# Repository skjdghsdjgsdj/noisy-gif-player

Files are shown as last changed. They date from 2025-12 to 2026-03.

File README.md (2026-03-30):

# Noisy GIF Player

## What is it?

It's a little portable device with a tiny screen and speaker to play animated GIFs, along with sound, from a microSD card.

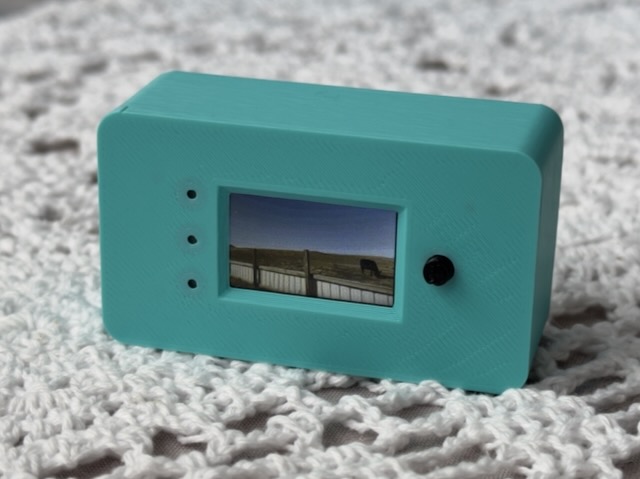
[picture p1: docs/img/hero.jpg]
Hero image (actual product)

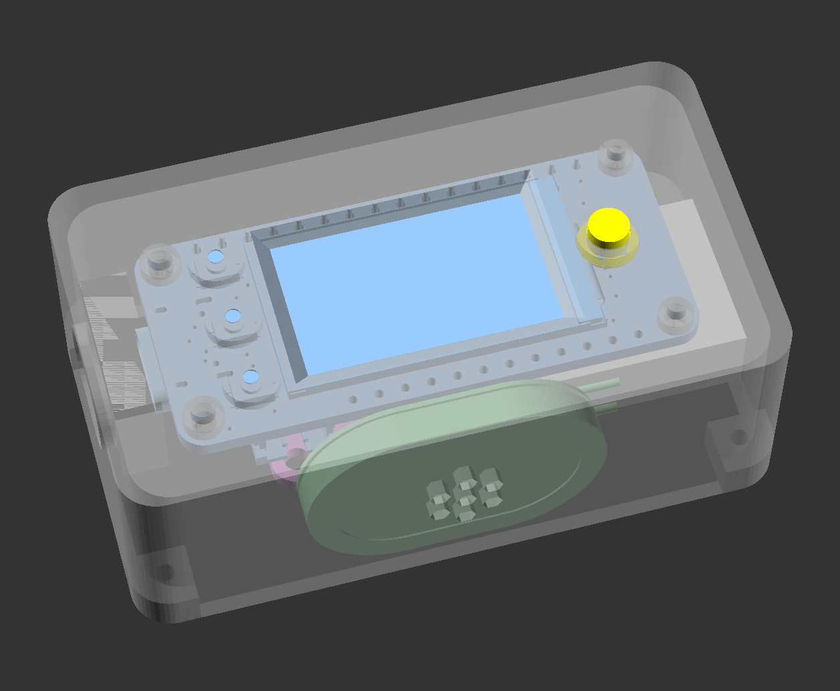
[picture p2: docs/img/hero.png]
Hero image (render)


## How do I build one?

You need:

* Some parts listed below
* Some soldering experience
* A 3D printer
* A computer:
  * Running macOS or Linux
  * With a microSD card reader
  * With FFmpeg installed

> [!NOTE]
> Linux/macOS is needed because the script that creates compatible GIFs/WAVs is written in Bash. On Windows, you'll need to port it to PowerShell, like `convert.ps1`. PRs welcome!

### Step 1: Buy parts

You need these parts:

| Part | Purpose | Price (USD) |
|---|---|---|
| [Adafruit ESP32-S3 Reverse TFT Feather](https://www.adafruit.com/product/5691) | The brains of the project, plus an LCD | $24.95 |
| [Adafruit SDIO breakout](https://www.adafruit.com/product/4682) | Stores GIFs and WAVs | $3.50 |
| [Adafruit I2S MAX98357A breakout](https://www.adafruit.com/product/3006) | Plays audio to a speaker | $5.95 |
| [Mini oval speaker](https://www.adafruit.com/product/3923) | An itty bitty speaker | $1.95 |
| [Female headers for Feathers](https://www.adafruit.com/product/2886) | Physical assembly | $0.95 |
| [400mAH battery for Feathers](https://www.adafruit.com/product/3898) | The battery | $6.95 |
| **Total** | | **$44.25**  |

You'll need these supplies:

* [Solid core hookup wire](https://www.adafruit.com/product/1311)
* Some screws:
  * 2&times; M2.5x4 screws
  * 2&times; M2x4 screws
  * 4&times; [countersunk self-tapping M2x6 screws](https://www.amazon.com/dp/B09DB5SMCZ?th=1)
* A microSD card (almost any size)
* A paperclip
* A USB C cable

### Step 2: Print the enclosure

Print the following parts. Use 0.2mm or smaller layer height. Infill settings don't matter. The STLs are in the latest release download on GitHub.

* Print `Case.stl` with the screen opening on the print bed. Use paint-on supports for the four screw holes in the corners of the case.
* Print `Backplate.stl` with the two ribs facing upwards.
* Print `Button.stl` with the wider part of the button on the print bed.

If your printer doesn't bridge well, also add supports to the USB C hole in `Case.stl`.

### Step 3: Make a GIF

The repository includes a script called `convert.sh` that runs FFmpeg with very specific arguments to make GIFs and WAVs compatible with the board.

> [!IMPORTANT]
> At least one GIF must be loaded onto the SD card for the project to function. Each GIF must follow a very specific format. A random GIF you find on the internet is unlikely to work. Here's how to make a compatible GIF and WAV.

First, prepare your environment. This only needs to be done once:

1. In a terminal, `cd` to the project's directory and the `software/server` directory, then run `chmod +x convert.sh` to make the conversion script executable.
2. Format your SD card as FAT32.
3. Create two directories in the root: `gifs` and `wavs`.

Now, convert a video into a compatible GIF and WAV format:

1. Download a video to your computer that you want to load. Pick a video that's only a few seconds long because longer ones might drift out of audio sync. Let's assume it's called `test.mp4` and you stored it in the same directory as this project.
2. Open a terminal and `cd` to the project's directory.
3. Run `./convert.sh test.mp4`. This outputs `test.gif` and the `test.wav` in the same directory.
4. Copy `test.gif` to `gifs/` and `test.wav` to `wavs/`.

The resulting SD card structure should look like:

```
SD card root
 ├── gifs/
 │   └── test.gif
 └── wavs/
     └── test.wav
```

### Step 4: Physical assembly

> [!IMPORTANT]
> Read these instructions fully before actually starting! Everything is a very tight fit in the enclosure and the details matter.

Here's a logical diagram of how the components are connected, for reference. In particular, note the following:

* The Feather's `GND` pin is shared, but two separate `3V` pins are used
* The I2S amplifier aligns to `MI` through `TX`; the _first_ 3V pin gets wired to the I2S amplifier's power pin
* The SD breakout aligns to the _second_ 3V pin, the GND pin, and various GPIO pins up through `SCK`; all the SD breakout's connections are through headers, not wires
* `RST`, `MO`, and `DB` are unused on the row of 16 pins
* None of the pins on the row of 12 pins are used

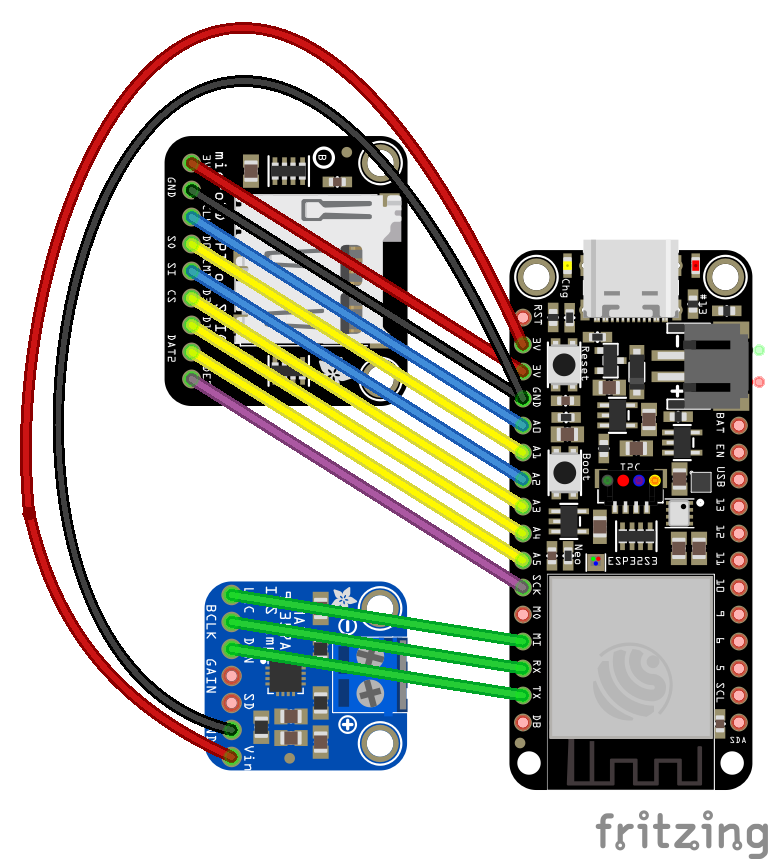
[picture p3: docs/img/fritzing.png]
Fritzing diagram


The male headers that come with the boards may not match the number of pins. You can twist apart the male headers at the perforations to get the right number of pins.

Some assembly tips:

* A magnetized screwdriver will help a lot. It's tricky to align the screws when everything is shoved in the case otherwise.
* For the doubled-up `GND` pin: try sandwiching the ground wire between the female header on the Feather and the Feather itself. That is, for the female header, the `GND` pin hole will have both the female header's pin and the ground wire going through it, then soldered in one bit. The female header might be a bit out of level, but as long as all the pins are making good contact once soldered, it should still fit.
* When viewing the case from above with the screen facing down and the USB port hole to the left, and therefore the speaker hole on the top, offset the speaker a bit to the right (i.e., away from the USB C hole). If you try to perfectly center it, you may find that the battery plug gets in the way of fitting everything into the case.

1. Solder headers to various boards. Be sure you get the pins right! You will not use all the headers!
   1. Solder the 16-pin female header to the Feather's row of 16 pins (`RST` through `DB`). **Do not solder the 12-pin female header.** The female portion of the header is on the opposite of the board as the LCD, like this:
   
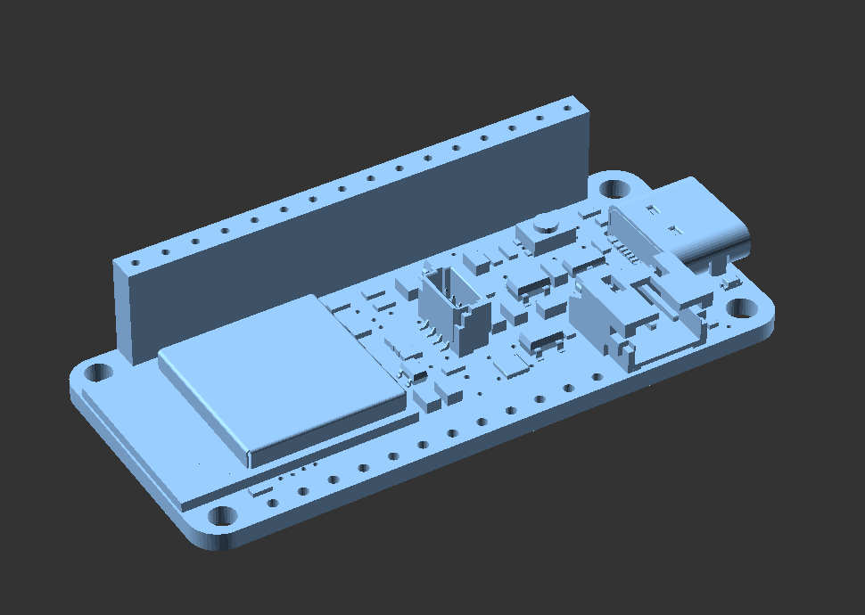
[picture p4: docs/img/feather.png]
Feather with female headers
      
      
   2. Solder a male header to the SD card breakout. The SD card slot faces up and the male header faces down, like this:
   
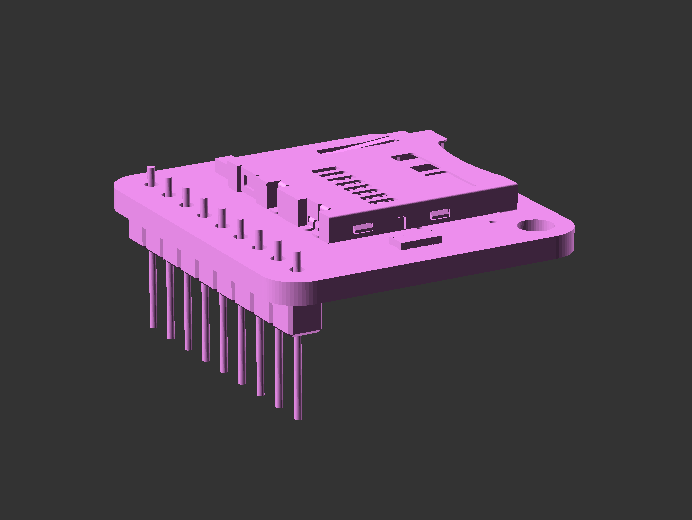
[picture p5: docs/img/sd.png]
SD card breakout with male headers
      

   3. Solder a male header **with only three** pins to the I2S amplifier breakout. Solder the `LRC`, `BCLK`, and `DIN` pins like this. Note that in this picture, the screw terminals if included with your board aren't shown, but would be on the top with the headers facing down. The components are also on the top.

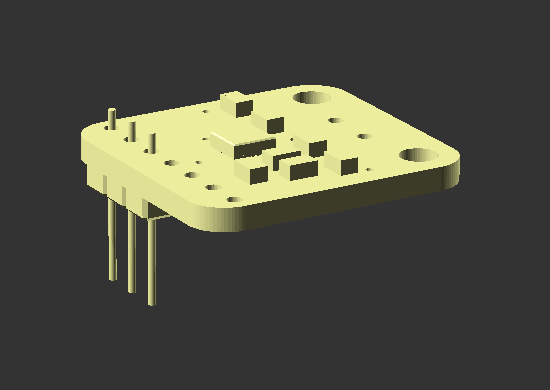
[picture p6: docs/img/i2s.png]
I2S amplifier with male headers
      

2. If your I2S amplifier came with presoldered screw terminals, you'll need to remove them because they take up too much space. Gently twist and rock them back and forth a whole bunch until you can work them free, or if you're able, desolder the pins. Be careful and take your time.

3. Now you'll connect the speaker to the I2S amplifier.

   1. Cut the tiny male JST connector off the speaker. You'll need every bit of wire possible, so cut off the connector as close to the wires as possible.
   2. Strip about 3 mm from the red and black wires from the speaker. The wire is very thin and you won't have much to work with, so be careful!
   3. Solder the black wire to the `-` pin on the I2S amplifier. This is one of the pins that are now exposed after you removed the screw terminals.
   4. Solder the red wire to the `+` pin.

4. Lastly, you need to solder a couple wires to the I2S amplifier for power and ground. This isn't necessary for the SD breakout because the pins already line up. Once you're done, the `GAIN` and `SD` pins should be unoccupied, but the other pins all connected to either headers or wires.

   1. Cut a black wire about 5 cm long and strip both ends at about 3 mm. Solder one end to the `GND` pin on the I2S amplifier. Solder the other end to the `GND` pin on the SD breakout. This means that the `GND` pin on the SD breakout will be soldered to both a male header pin and the wire, so it'll be tricky to solder.
   2. Cut a red wire about 5 cm long. Strip one end to 3 mm, and the other to about 6 mm. Solder the 3mm end to the `VIN` pin of the I2S amplifier. Leave the other end free for now.

5. Install the parts into the enclosure:

   1. Place the tiny 3D printed button in its hole. The narrow end goes through the front of the case. The wider part keeps it in place, like this:

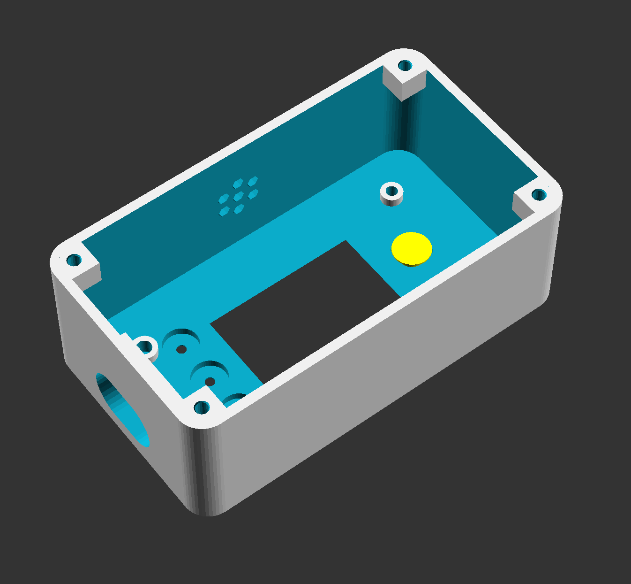
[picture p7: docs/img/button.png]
Button in place
      

   2. Connect the battery to the Feather. Definitely from this point onwards be careful aligning things and poking around with screwdrivers so you don't short any components!
   
   3. Screw the Feather into place. Use the M2.5x4mm screws for the larger holes and M2x4mm screws for the smaller ones. Only tighten them enough to keep the board in place. Overtightening will easily strip the plastic and you'll need to reprint the case. Once done, test pressing the button to make sure it moves freely and actuates the reset button on the Feather itself.

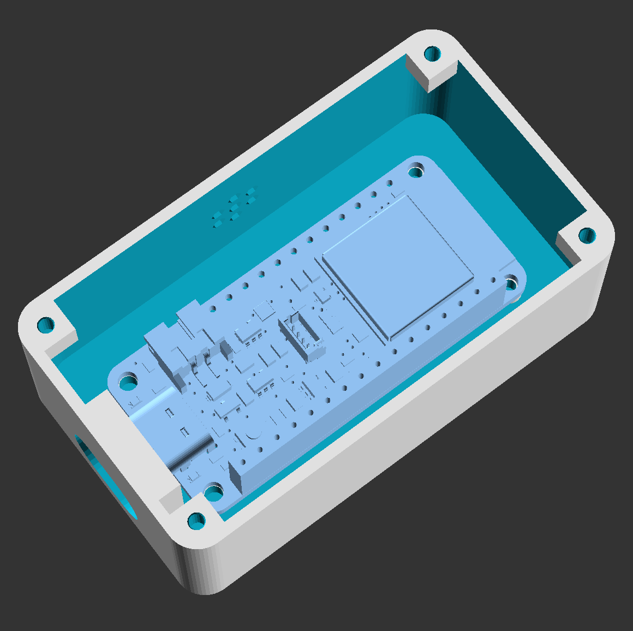
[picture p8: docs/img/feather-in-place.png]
Feather in place
      

   4. Insert your microSD card into the SD reader, then install the SD reader and I2S amplifier. Note the alignment. **Be sure to align them to the pins shown!** The first two pins closest to the USB C port should be empty, along with the last pin closest to the ESP32. When doing so, tuck the battery under the breakouts (the white box).

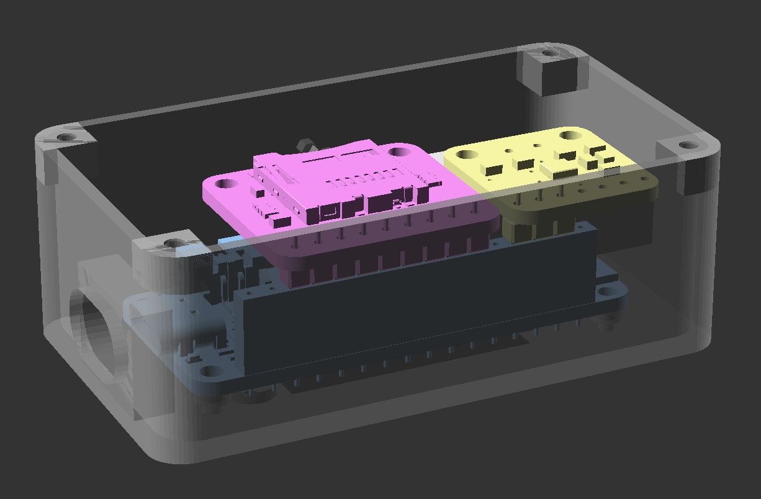
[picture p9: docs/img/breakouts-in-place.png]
Breakouts in place
      
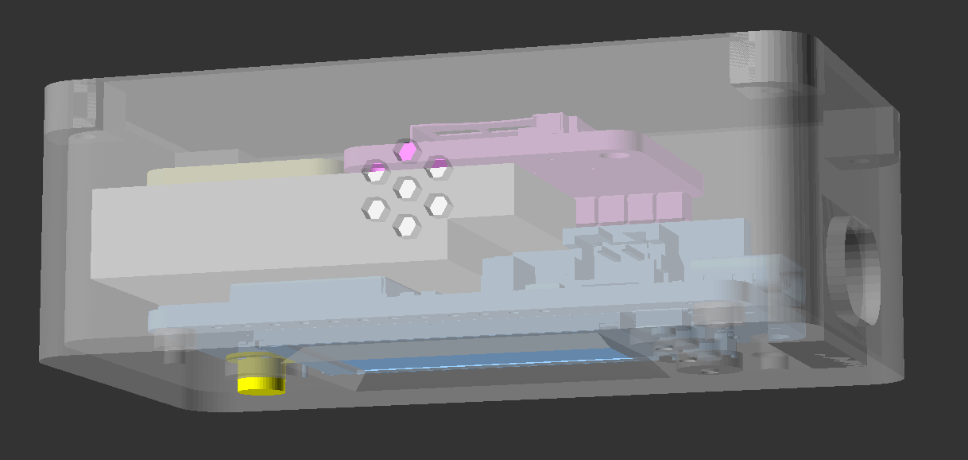
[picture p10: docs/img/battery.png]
      

   5. Take the loose end of the red wire and put it in the second pin closest to the USB C port (`3V`) of the female header.

   6. Remove the white cover for the adhesive on the sticker, and shove it into place by the speaker hole with the grille facing outwards. It may be tricky to maneuver it around the battery connection.

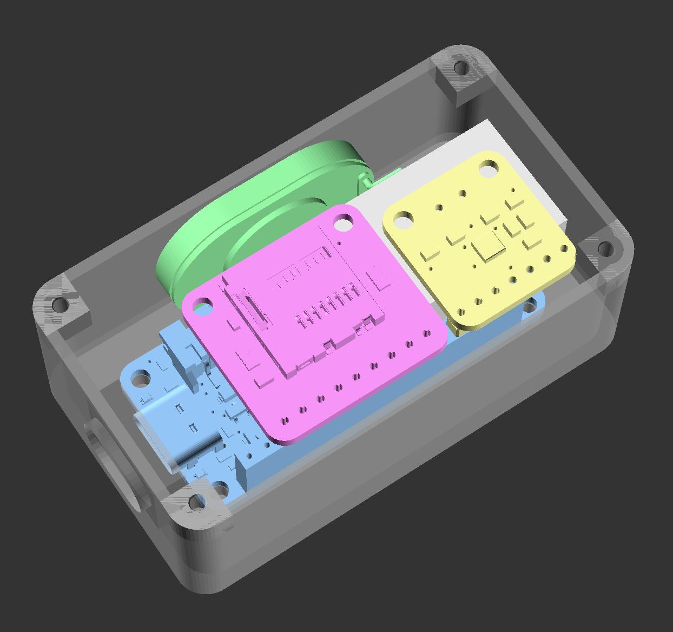
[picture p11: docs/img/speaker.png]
Speaker in place
      

6. You're done! Screw the backplate on with the ribs facing inward by the components using the self-tapping screws.

### Step 5: Software installation

1. Install the Arduino IDE and set it up for this specific board per [Adafruit's instructions](https://learn.adafruit.com/esp32-s3-reverse-tft-feather/arduino-ide-setup-2).
2. Open `software/Arduino/Arduino.ino` and install the following libraries via Sketch → Include Library → Manage Libraries. Install dependencies if prompted.
   1. "Adafruit GFX Library" by Adafruit
   2. "Adafruit ST7735 and ST7789 Library" by Adafruit
   3. "AnimatedGIF" by Larry Bank
3. Connect the board to your computer via a USB C cable.
4. Using a paperclip, press and hold D0 (top-left pinhole on the board when viewed with the USB port on the left). While holding D0, press the Reset button, then release D0.
5. Connect to the board in the Arduino IDE.
6. Select **Tools** → **Partition Scheme** and "Huge APP (3MB No OTA/1MB SPIFFS)" or a similar entry. This prevents a bootloader screen from appearing if you press the Reset button twice with a specific timing.
7. Select **Tools** → **USB CDC on Boot** and set it to "Disabled." If you don't do this, the USB loading method of files to the SD card may not work.
8. Compile and upload the sketch.

Press the Reset button. Your GIF and WAV should play! Once the GIF is done, the screen fades off and the board sleeps. Pressing the Reset button wakes it back up and a GIF/WAV play again.

## Usage

The physical 3D printed button presses the Reset button on the Feather, playing a random GIF. The code will avoid playing the same GIF twice if more than one GIF is loaded.

The battery should last a long time, but it's not a good idea to let it discharge too deeply. Charge the board with a USB C cable periodically. It is safe to keep a USB cable connected even after the battery is done charging.

### Loading more GIFs

There are two ways to load GIFs and WAVs.

The fastest way for a lot of GIFs and WAVs is directly via the SD card. Consider this option when you first build the project. Once you've built the project, it can be a pain to take it apart to get the SD card out.

The more convenient way is by a USB cable, but transfer speeds are much slower than using the SD card directly:

* Connect the project to your computer via USB C.
* Use a paperclip to hold down the D2 button. When viewed with the USB C port on the left, this is the bottom-left pinhole.
* While holding down D2, press Reset, then release D2.

This reboots the board into USB mass storage mode with a message appearing on the screen stating that USB is connected. A new drive will appear on your computer when connected by USB. The name will be the same as whatever the SD card was named when you formatted it. Once you're done managing the files, eject the drive from your computer, then press the Reset button.

All the GIFs and WAVs you load must be created using the `convert.sh` script! Don't use GIFs or WAVs you find on the internet because they will not likely be compatible with these specs. Always process all your files through `convert.sh`, even if the source itself is a GIF, to be sure it's compatible with the project.

The conversion script can also be invoked with a friendly web interface. If you want to run that, you'll need a Python installation. These instructions assume you have some Python knowledge.

1. Open a terminal and `cd` to the project's `software/server` directory.
2. Set up a Python virtual environment with `python3 -m venv venv` then activate it with `source venv/bin/activate`.
3. Install the necessary libraries with `pip3 install -r requirements.txt`.
4. Run the server: for testing's sake, use `python3 app.py`, or for "production" use (well, just not your own computer), run `chmod +x start.sh` to make the startup script executable, then launch it with `./start.sh`.
5. Open a browser to `http://localhost:5000/`.

### About GIF creation

> [!TIP]
> The WAV for a GIF is optional, so if your source file has no sound, or you just don't want sound, delete the resulting `.wav` file.

`convert.sh` does several things:

* Forces the framerate to 30 fps
* Forces the resolution to exactly 240x135, which is the native resolution of the screen. GIFs are letterboxed or pillarboxed as necessary to keep the aspect ratio and to match this resolution.
* Forces a specific color palette
* Outputs a WAV file at 16 KHz mono

You can pass `--start` and/or `--end` arguments to the conversion script with timecodes to crop a video to a certain timespan if you don't want to convert the entire thing.

## Known issues

* **The OpenSCAD code is terrible and a lot of the math is wrong if you adjust some settings, like surface thickness.** Sure is. I needed to build this quickly so I hardcoded a _lot_ of things. I welcome any attempts to clean up or just completely redo the enclosure code.
* **Some of the Arduino code is also terrible.** Because it is largely and shamefully AI generated for the same reason of time constraints, plus C++ not being my speciality. At least it works.
* **The USB transfer speed is super slow.** That's a limitation of the board. I don't think there's any way to make it faster. If you want to transfer a lot of data, take out the SD card and put it in a card reader.
* **There's no low battery warning.** Yes I should add that. There's an onboard I2C battery monitor that should work for this purpose; I just haven't programmed that in yet.

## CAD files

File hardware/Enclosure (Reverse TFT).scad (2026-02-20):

include <BOSL2/std.scad>
include <BOSL2/shapes3d.scad>

// Diameter of pins (male)
Pin_diameter = 0.5;
// How far pins project from the base of a header into the thru holes
Pin_projection = 3;
// Height of the female-only portion of female headers
Female_header_base_height = 8.5;
// Height of the plastic retaining thing of male headers
Male_header_base_height = 2.6;
// Depth of the plastic retaining thing for headers
Header_base_depth = 2.5;
Male_header_total_height = 11.4;

PCB_height = 1.6;

Surface = 1.5;

/* [Self-tapping screws for the lid including tolerances (M2x6 are defaults)] */
Screw_height = 6.3;
Screw_head_diameter = 4.1;
Screw_head_height = 1.7;
Screw_shaft_diameter = 1.85;
// Distance inset from the corner
Screw_inset = 2;
	
Feather_width = 2 * 25.4;
Feather_depth = 0.9 * 25.4;

Extra_width = 11;
Extra_depth = 11;

Inner_height = 21;

Radius = 4;

Z_offset = -1.5;

USB_C_Z = 3.6;

$fn = 50;

module female_header(pin_count, pitch = 2.54) {
	assert(pin_count >= 1);
	
	for (i = [0 : pin_count - 1]) {
		translate([pitch * i, 0, -Pin_projection])
		cylinder(d = Pin_diameter, h = Pin_projection);
	}
	
	render()
	difference() {
		translate([-pitch / 2, -Header_base_depth / 2, 0])
		cube([pitch * pin_count, Header_base_depth, Female_header_base_height]);
	
		for (i = [0 : pin_count - 1]) {
			translate([pitch * i, 0, 0])
			cylinder(d = Pin_diameter + 0.2, h = Female_header_base_height);
		}
	}
}

module male_header(pin_count, pitch = 2.54) {
	assert(pin_count >= 1);
	
	for (i = [0 : pin_count - 1]) {
		translate([pitch * i, 0, 0])
		
		union() {
			cylinder(d = Pin_diameter, h = Male_header_total_height);
			
			translate([0, 0, -Male_header_base_height / 2 + Male_header_total_height - Pin_projection + pitch / 10])
			cuboid([pitch, Header_base_depth, Male_header_base_height], chamfer = pitch / 10);
		}
	}
}

// Feather specs: https://learn.adafruit.com/adafruit-feather/feather-specification
%color("#99ccff") {
	translate([6.35, 0.05 * 25.4, PCB_height])
	female_header(16);

	//translate([16.45, (0.9 * 25.4) - (0.05 * 25.4), PCB_height])
	//female_header(12);

	import("lib/5691 ESP32 S3 Reverse TFT Feather.stl");
}

%translate([8.9, -1.3, Female_header_base_height + Male_header_base_height + PCB_height])
rotate([0, 0, 0])
color("#ff99ff") {
	translate([2.5, 2.55, -Male_header_total_height + Pin_projection - 0.2])
	male_header(9);

	import("lib/4682 Micro SD Breakout.stl");
}

%translate([35.5, -1.3, PCB_height + Female_header_base_height])
color("#ffffaa") {
	translate([0, 0, Male_header_base_height])
	import("lib/3006 MAX98357.stl");
	translate([1.3, 2.55, -Male_header_total_height + Pin_projection + Male_header_base_height - 0.2])
	male_header(3);
}

%translate([24.5, 5, 4.5]) {
	cube([31, 17, 7.5]);
	
	translate([-5.6, 0, 7.5 - 4.2])
	cube([5.6, 17, 4.2]);
}

%translate([25, 28, 9])
rotate([90, 90, 0])
color("#99ffaa") import("lib/3923 Mini Oval Speaker.stl");

module usb_c_hole(depth) {
	$fn = 36;

	hole_width = 13;
	hole_radius = 4;

	for (y = [-hole_width / 2 + hole_radius, hole_width / 2 - hole_radius]) {
		translate([0, y, 0])
		rotate([90, 0, 90])
		cylinder(r = hole_radius, h = depth);
	}
	
	translate([depth / 2, 0, 0])
	cube([depth, hole_width - hole_radius * 2, hole_radius * 2], center = true);
}

module screw() {
	cylinder(d = Screw_shaft_diameter, h = Screw_height, $fn = 20);
	
	translate([0, 0, Screw_height - Screw_head_height])
	cylinder(d2 = Screw_head_diameter, d1 = Screw_shaft_diameter, h = Screw_head_height, $fn = 20);
}

module screws() {
	inset = 2;
	for (x = [-Extra_width / 2 + inset, 2 * 25.4 + Extra_width / 2 - inset]) {
		for (y = [-Extra_depth / 2 + inset, 0.9 * 25.4 + Extra_depth / 2 - inset]) {
			translate([x, y, Inner_height + Z_offset - Screw_height + Surface])
			screw();
		}
	}
}

module case() {
	difference() {
		translate([-(Extra_width / 2 - 1) / 2 - 1, (0.9 * 25.4) / 2, (USB_C_Z + 5) / 2 + Z_offset])
		cube([Extra_width / 2 - 1, 15, USB_C_Z + 8], center = true);
		
		translate([-(Surface + Extra_width / 2), (0.9 * 25.4) / 2, USB_C_Z])
		usb_c_hole(Surface + Extra_width / 2);
	}
	
	for (y = [0.1 * 25.4, (0.9 * 25.4) - (0.1 * 25.4)]) {
		translate([0.1 * 25.4, y, Z_offset])
		render()
		difference() {
			cylinder(d = 4, h = abs(Z_offset));
			cylinder(d = 2.35, h = abs(Z_offset));
		}
	}
	
	for (y = [1.85, (0.9 * 25.4) - 1.85]) {
		translate([(2 * 25.4) - (0.1 * 25.4), y, Z_offset])
		render()
		difference() {
			cylinder(d = 3.5, h = abs(Z_offset));
			cylinder(d = 1.85, h = abs(Z_offset));
		}
	}
	
	difference() {
		intersection() {
			translate([-Extra_width / 2 - Surface, -Extra_depth / 2 - Surface, -Surface + Z_offset])
			cuboid(
				[Feather_width + Extra_width + Surface * 2, Feather_depth + Extra_depth + Surface * 2, Inner_height + Surface],
				rounding = Radius,
				edges = ["Z"],
				anchor = [-1, -1, -1]
			);
			
			union() {
				for (x = [-Extra_width / 2 - Surface, 2 * 25.4 + Extra_width / 2 + Surface - 6]) {
					for (y = [-Extra_depth / 2 - Surface, 0.9 * 25.4 + Extra_depth / 2 + Surface - 6]) {
						translate([x, y, Inner_height - Surface - 4])
						cube([6, 6, 4]);
					}
				}
			}
		}
		
		screws();
	}
	
	translate([0, 0, Z_offset])
	render()
	difference() {
		translate([-Extra_width / 2 - Surface, -Extra_depth / 2 - Surface, -Surface])
		cuboid(
			[Feather_width + Extra_width + Surface * 2, Feather_depth + Extra_depth + Surface * 2, Inner_height + Surface],
			rounding = Radius,
			edges = ["Z"],
			anchor = [-1, -1, -1]
		);
	
		for (y = [0.1 * 25.4, (0.9 * 25.4) - (0.1 * 25.4)]) {
			translate([0.1 * 25.4, y, -Surface + 0.2])
			cylinder(d = 2.35, h = abs(Z_offset));
		}
	
		for (y = [1.85, (0.9 * 25.4) - 1.85]) {
			translate([(2 * 25.4) - (0.1 * 25.4), y, -Surface + 0.2])
			cylinder(d = 1.85, h = abs(Z_offset));
		}
	
		translate([-Extra_width / 2, -Extra_depth / 2, 0])
		cuboid(
			[Feather_width + Extra_width, Feather_depth + Extra_depth, Inner_height],
			rounding = Radius,
			edges = ["Z"],
			anchor = [-1, -1, -1]
		);
		
		translate([(2 * 25.4) / 2, (0.9 * 25.4) / 2, -Surface])
		prismoid(
			size2 = [24.91, 14.86],
			size1 = [24.91 + Surface * 2, 14.86 + Surface * 2],
			height = Surface
		);
		
		translate([44.45, (0.9 * 25.4) / 2, -Surface])
		cylinder(
			d = 4.2,
			h = Surface
		);
		
		translate([44.45, (0.9 * 25.4) / 2, -Surface + 0.2])
		cylinder(
			d = 6.2,
			h = Surface
		);
		
		for (y_delta = [-7, 0, 7]) {
			translate([7.6, (0.9 * 25.4) / 2 + y_delta, -Surface])
			union() {
				cylinder(
					d = 1.5,
					h = Surface
				);
				
				translate([0, 0, 0.2])
				cylinder(
					d = 5.5,
					h = Surface - 0.2
				);
			}
		}
		
		translate([Feather_width / 2, Feather_depth + Extra_depth + Surface - Extra_depth / 2, Inner_height / 2])
		rotate([90, 0, 0])
		union() {
			cylinder(d = 2, $fn = 6, h = Surface);
			
			for (i = [0 : 5]) {
				angle = (i / 6) * 360;
				translate([sin(angle) * 3, cos(angle) * 3, 0])
				cylinder(d = 2, $fn = 6, h = Surface);
			}
		}
		
		translate([-(Surface + Extra_width / 2), (0.9 * 25.4) / 2, USB_C_Z - Z_offset])
		usb_c_hole(Surface + Extra_width / 2);
		
		screws();
	}
}

module button() {
	translate([44.45, (0.9 * 25.4) / 2, -Surface + Z_offset - 1])
	cylinder(
		d = 4,
		h = Surface + 1.5
	);
	
	translate([44.45, (0.9 * 25.4) / 2, -Surface + Z_offset - 1 + 2.7])
	cylinder(
		d = 6,
		h = 0.3
	);
}

module backplate() {
	render()
	difference() {
		translate([-Extra_width / 2 - Surface, -Extra_depth / 2 - Surface, Inner_height - Surface])
		union() {
			cuboid(
				[Feather_width + Extra_width + Surface * 2, Feather_depth + Extra_depth + Surface * 2, Surface],
				rounding = Radius,
				edges = ["Z"],
				anchor = [-1, -1, -1]
			);
			
			for (y = [Extra_depth / 2 + 2 + 2, 0.9 * 25.4 + Extra_depth / 2 - 2]) {
				translate([Surface, y, -2])
				cube([Feather_width + Extra_width, 2, 2]);
			}
		}
		
		screws();
	}
}

//case();
//backplate();

button();

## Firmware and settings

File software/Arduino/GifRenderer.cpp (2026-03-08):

#include "GifRenderer.h"
#include "I2SWavPlayer.h"
#include <SD_MMC.h>
#include "esp_timer.h"

GifRenderer::GifRenderer()
  : tft(NULL), decodeBuffer(0), skipFrame(false),
    prevFrameWasOpaque(false), currentFrameHasTransparency(false),
    displayQueue(NULL), displayWriterHandle(NULL) {
  bufferFree[0] = NULL;
  bufferFree[1] = NULL;
}

GifRenderer &GifRenderer::instance() {
  static GifRenderer inst;
  return inst;
}

void GifRenderer::begin(Adafruit_ST7789 &display) {
  tft = &display;
  // BIG_ENDIAN_PIXELS stores palette colors in the byte order the ST7789 expects
  // over SPI (high byte first). writePixels(..., bigEndian=true) then passes the
  // framebuffer directly to DMA without any per-pixel byte-swap pass.
  gif.begin(BIG_ENDIAN_PIXELS);
  clearFrameBuffer();

  displayQueue  = xQueueCreate(1, sizeof(DisplayFrame));
  bufferFree[0] = xSemaphoreCreateBinary();
  bufferFree[1] = xSemaphoreCreateBinary();
  xSemaphoreGive(bufferFree[0]);
  xSemaphoreGive(bufferFree[1]);
}

bool GifRenderer::playGif(const String &gifPath) {
  if (!gif.open(
        gifPath.c_str(),
        GIFOpenFile,
        GIFCloseFile,
        GIFReadFile,
        GIFSeekFile,
        GIFDraw
      )) {
    return false;
  }

  startDisplayWriterTask();

  I2SWavPlayer &player = I2SWavPlayer::instance();
  bool haveAudio = player.isActive();

  // Use the audio render start time as the GIF timeline origin so that
  // frame 0 is displayed exactly when the first audio sample is heard,
  // eliminating the fixed phase offset caused by I2S DMA pipeline latency.
  // Without audio, fall back to the current wall clock.
  uint64_t startUs     = haveAudio ? player.getAudioRenderStartUs()
                                   : esp_timer_get_time();
  uint64_t nextFrameUs = startUs;  // deadline for frame 0

  int  lastPosted    = -1;
  bool playing       = true;
  bool dropNextFrame = false;

  while (playing) {
    // Sleep until this frame's deadline, overlapping with the DisplayWriter's
    // SPI transfer for the previous frame. If we're already behind, skip sleep.
    int64_t sleepUs = (int64_t)nextFrameUs - (int64_t)esp_timer_get_time();
    if (sleepUs >= 1000) {
      vTaskDelay(pdMS_TO_TICKS(sleepUs / 1000));
    } else if (sleepUs > 0) {
      esp_rom_delay_us((uint32_t)sleepUs);
    }

    xSemaphoreTake(bufferFree[decodeBuffer], portMAX_DELAY);

    // Carry forward the previous frame as the background for transparent pixels.
    // Safe: DisplayWriter may still be reading frameBuffer[decodeBuffer ^ 1] via SPI
    // DMA, but we only read it here too — concurrent reads have no data race.
    //
    // Skip the copy when the previous frame was fully opaque: every pixel in the
    // decode buffer will be overwritten regardless, so copying is pure waste.
    // For full-motion video GIFs this is almost always the case, saving a 64 KB
    // memcpy per frame (~0.3 ms each on internal SRAM).
    if (!prevFrameWasOpaque) {
      memcpy(frameBuffer[decodeBuffer], frameBuffer[decodeBuffer ^ 1],
             sizeof(frameBuffer[0]));
    }

    // Reset per-frame transparency flag; draw() sets it if any scanline is transparent.
    currentFrameHasTransparency = false;

    // skipFrame is read inside flushFrameIfLastLine() (called from gif.playFrame).
    // When true, that callback releases bufferFree[decodeBuffer] itself instead of
    // posting to the display queue, so the DisplayWriter never sees this frame.
    skipFrame = dropNextFrame;

    int frameDelayMs = 0;
    playing = gif.playFrame(false, &frameDelayMs);
    nextFrameUs += (uint64_t)frameDelayMs * 1000ULL;

    prevFrameWasOpaque = !currentFrameHasTransparency;

    if (!skipFrame) {
      lastPosted = decodeBuffer;
    }

    // After every frame, compare heard audio position to the GIF timeline.
    // If audio has overtaken the end of this frame, mark the next frame for
    // dropping. This self-corrects any drift or decode-time spikes without
    // touching audio at all.
    dropNextFrame = false;
    if (haveAudio && frameDelayMs > 0 && player.isActive()) {
      int64_t audioUs = player.getAudioPositionUs();
      int64_t videoUs = (int64_t)(nextFrameUs - startUs);  // GIF timeline pos of next frame start
      if (audioUs >= 0) {
        dropNextFrame = (audioUs > videoUs);
      }
    }

    decodeBuffer ^= 1;
  }

  if (lastPosted != -1) {
    waitForLastFrame(lastPosted);
  }

  stopDisplayWriterTask();
  gif.close();
  return true;
}

void *GifRenderer::openFile(const char *fname, int32_t *pSize) {
  gifFile = SD_MMC.open(fname, FILE_READ);
  if (gifFile) {
    *pSize = gifFile.size();
    return (void *)&gifFile;
  }
  return NULL;
}

void GifRenderer::closeFile(void *pHandle) {
}

int32_t GifRenderer::readFile(GIFFILE *pFile, uint8_t *pBuf, int32_t iLen) {
  int32_t iBytesRead = iLen;
  File *f = static_cast<File *>(pFile->fHandle);

  if ((pFile->iSize - pFile->iPos) < iLen) {
    iBytesRead = pFile->iSize - pFile->iPos;
  }
  if (iBytesRead <= 0) {
    return 0;
  }

  iBytesRead = (int32_t)f->read(pBuf, iBytesRead);
  pFile->iPos += iBytesRead;
  return iBytesRead;
}

int32_t GifRenderer::seekFile(GIFFILE *pFile, int32_t iPosition) {
  File *f = static_cast<File *>(pFile->fHandle);
  f->seek(iPosition);
  pFile->iPos = iPosition;
  return iPosition;
}

bool GifRenderer::clipAndPrepareLine(
  GIFDRAW *pDraw,
  int &iWidth,
  int &y,
  uint8_t *&pixels,
  uint16_t *&lineBase
) {
  if (tft == NULL) {
    return false;
  }

  iWidth = min(pDraw->iWidth, DISPLAY_WIDTH - pDraw->iX);
  if (pDraw->iX >= DISPLAY_WIDTH || iWidth < 1) {
    return false;
  }

  y = pDraw->iY + pDraw->y;
  if (y >= DISPLAY_HEIGHT) {
    return false;
  }

  pixels = pDraw->pPixels;
  lineBase = &frameBuffer[decodeBuffer][y * DISPLAY_WIDTH + pDraw->iX];
  return true;
}

void GifRenderer::applyDisposalIfNeeded(GIFDRAW *pDraw, uint8_t *pixels, int iWidth) {
  if (pDraw->ucDisposalMethod != 2) {
    return;
  }

  int x = 0;
  while (x < iWidth) {
    if (pixels[x] == pDraw->ucTransparent) {
      pixels[x] = pDraw->ucBackground;
    }
    x++;
  }

  pDraw->ucHasTransparency = 0;
}

void GifRenderer::drawTransparentLine(
  GIFDRAW *pDraw,
  uint8_t *pixels,
  int iWidth,
  uint16_t *lineBase,
  uint16_t *palette
) {
  uint8_t *src = pixels;
  uint8_t *srcEnd = src + iWidth;
  uint8_t transparentIndex = pDraw->ucTransparent;
  int x = 0;

  while (src < srcEnd) {
    uint8_t colorIndex = *src++;
    if (colorIndex != transparentIndex) {
      lineBase[x] = palette[colorIndex];
    }
    x++;
  }
}

void GifRenderer::drawOpaqueLine(
  uint8_t *pixels,
  int iWidth,
  uint16_t *lineBase,
  uint16_t *palette
) {
  const uint8_t *src = pixels;
  const uint8_t *end = pixels + iWidth;
  uint16_t      *dst = lineBase;

  while (src < end) {
    *dst++ = palette[*src++];
  }
}
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

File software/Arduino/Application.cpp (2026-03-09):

#include "Application.h"

#include <SPI.h>
#include <Adafruit_GFX.h>
#include <Adafruit_ST7789.h>
#include "driver/ledc.h"
#include "SDCard.h"
#include "PreferenceManager.h"
#include "GifSelector.h"
#include "GifRenderer.h"
#include "I2SWavPlayer.h"
#include "USBMassStorageMode.h"

// Pins
static constexpr uint8_t USB_MSC_BUTTON_PIN = 2;            // Front-panel button used only to enter USB MSC mode
static constexpr uint8_t BACKLIGHT_PIN     = TFT_BACKLITE;  // TFT backlight control pin
static constexpr uint8_t TFT_I2C_POWER_PIN = TFT_I2C_POWER; // TFT I2C power control pin

// Backlight / fade constants
static constexpr uint32_t FADE_DURATION_MS = 500;      // Duration of backlight fade before deep sleep (ms)
static constexpr uint32_t TFT_SPI_SPEED_HZ = 80000000; // SPI clock for TFT (Hz)
static constexpr uint8_t  TFT_ROTATION     = 3;        // Display rotation setting for landscape layout

// Full-range PWM brightness; 255 is the natural max for 8-bit resolution.
static constexpr uint32_t BACKLIGHT_MAX = 255; // Full-scale duty cycle for LEDC 8-bit timer

// LEDC peripheral config for the backlight pin.
// Uses a dedicated channel and timer so no other subsystem can claim them.
static constexpr ledc_channel_t BACKLIGHT_LEDC_CHANNEL = LEDC_CHANNEL_0;
static constexpr ledc_timer_t   BACKLIGHT_LEDC_TIMER   = LEDC_TIMER_0;

// Global display
static Adafruit_ST7789 tft(TFT_CS, TFT_DC, TFT_RST);

Application::Application() {
}

void Application::fadeBacklightOff() {
  // Hardware LEDC fade: the peripheral drives the PWM duty from current level
  // to 0 over FADE_DURATION_MS with no CPU polling. LEDC_FADE_WAIT_DONE blocks
  // until the fade completes before we proceed to power down peripherals.
  ledc_set_fade_with_time(LEDC_LOW_SPEED_MODE, BACKLIGHT_LEDC_CHANNEL, 0, FADE_DURATION_MS);
  ledc_fade_start(LEDC_LOW_SPEED_MODE, BACKLIGHT_LEDC_CHANNEL, LEDC_FADE_WAIT_DONE);
}

void Application::powerDownPeripherals() {
  pinMode(NEOPIXEL_POWER, OUTPUT);
  digitalWrite(NEOPIXEL_POWER, LOW);
  digitalWrite(TFT_I2C_POWER_PIN, LOW);

  SPI.end();
  SDCard::instance().end();
}

[[noreturn]] void Application::startESPDeepSleep() {
  esp_sleep_pd_config(ESP_PD_DOMAIN_RTC_PERIPH, ESP_PD_OPTION_OFF);
  esp_sleep_pd_config(ESP_PD_DOMAIN_VDDSDIO, ESP_PD_OPTION_OFF);
  esp_deep_sleep_start();
}

[[noreturn]] void Application::enterDeepSleep() {
  fadeBacklightOff();
  powerDownPeripherals();
  startESPDeepSleep();
}

void Application::setupPinsAndPower() {
  pinMode(USB_MSC_BUTTON_PIN, INPUT_PULLDOWN);

  // Configure the LEDC timer and channel for hardware PWM backlight control.
  // This replaces analogWrite: LEDC lets us trigger smooth hardware fades later
  // without any CPU involvement. 8-bit resolution gives 0-255 duty range.
  ledc_timer_config_t timer_conf = {
    .speed_mode      = LEDC_LOW_SPEED_MODE,
    .duty_resolution = LEDC_TIMER_8_BIT,
    .timer_num       = BACKLIGHT_LEDC_TIMER,
    .freq_hz         = 1000,
    .clk_cfg         = LEDC_AUTO_CLK,
  };
  ledc_timer_config(&timer_conf);

  ledc_channel_config_t ch_conf = {
    .gpio_num   = BACKLIGHT_PIN,
    .speed_mode = LEDC_LOW_SPEED_MODE,
    .channel    = BACKLIGHT_LEDC_CHANNEL,
    .intr_type  = LEDC_INTR_DISABLE,
    .timer_sel  = BACKLIGHT_LEDC_TIMER,
    .duty       = BACKLIGHT_MAX,  // Full brightness on boot
    .hpoint     = 0,
  };
  ledc_channel_config(&ch_conf);

  // Install the fade ISR once; required before any ledc_set_fade_with_time call.
  ledc_fade_func_install(0);

  pinMode(TFT_I2C_POWER_PIN, OUTPUT);
  digitalWrite(TFT_I2C_POWER_PIN, HIGH);
}

void Application::setupDisplay() {
  SPI.begin();
  tft.setSPISpeed(TFT_SPI_SPEED_HZ);
  tft.init(GifRenderer::DISPLAY_HEIGHT, GifRenderer::DISPLAY_WIDTH);
  tft.setRotation(TFT_ROTATION);
  tft.fillScreen(ST77XX_BLACK);
}

void Application::setupStorage() {
  SDCard::instance().begin();
}

void Application::setupSubsystems() {
  GifRenderer::instance().begin(tft);
  (void)PreferenceManager::instance();
  (void)GifSelector::instance();
  (void)I2SWavPlayer::instance();
  (void)USBMassStorageMode::instance();
}

void Application::setup() {
  setupPinsAndPower();
  setupDisplay();
  setupStorage();
  setupSubsystems();

  if (digitalRead(USB_MSC_BUTTON_PIN) == HIGH) {
    USBMassStorageMode::instance().run(tft);
  }
}

void Application::loopOnce() {
  String gifPath;
  String wavPath;

  GifSelector &selector = GifSelector::instance();
  if (!selector.chooseRandomGifAndWav(gifPath, wavPath)) {
    enterDeepSleep();
  }

  I2SWavPlayer &player = I2SWavPlayer::instance();
  bool haveWav = player.start(wavPath);

  if (!GifRenderer::instance().playGif(gifPath)) {
    // The chosen path may be a stale cache entry (e.g. the file was deleted).
    // Clear the cache so the next boot re-enumerates rather than hitting the
    // same dead entry repeatedly.
    PreferenceManager::instance().clearCandidateList();
    enterDeepSleep();
  }

  if (haveWav) {
    player.waitUntilDone();
  }

  enterDeepSleep();
}

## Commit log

2025-11-29 Initial concept for component layout
    [Enclosure.scad]
2025-11-29 Added basics of the case (which requires BOSL2)
    [Enclosure.scad]
2025-11-30 Reset hole guide
    [Enclosure.scad]
2025-11-30 Speaker holes
    [Enclosure.scad]
2025-11-30 Audio amp standoffs and USB C hole
    [Enclosure.scad]
2025-11-30 Little Feather retaining pin
    [Enclosure.scad]
2025-12-01 Feather standoffs
    [Enclosure.scad]
2025-12-01 Button standoff/retainer
    [Enclosure.scad]
2025-12-01 LCD standoffs
    [Enclosure.scad]
2025-12-01 Battery tweaks
    [Enclosure.scad]
2025-12-02 Fixed button lip position
    [Enclosure.scad]
2025-12-02 First draft
    [Enclosure.scad]
2025-12-02 Lid reinforcement ribs
    [Enclosure.scad]
2025-12-02 Some real world fixes, more to come
    [Enclosure.scad]
2025-12-03 Get rid of all the USB switching garbage and just rely on CircuitPython 10's built in support, in theory
2025-12-03 Enter deep sleep when holding down the button
2025-12-03 More real-world fixes
    [Enclosure.scad]
2025-12-04 Last WIP before switching to ESP32-S3 Reverse TFT Feather
    [Fritzing.fzz]
2025-12-18 Changing setup to use ESP32-S3 Reverse TFT Feather
2025-12-22 First, and crappy, enclosure design
    [Enclosure (Reverse TFT).scad]
2025-12-23 Arduino WIP because CircuitPython won't cut it
2025-12-23 Arduino code that largely works
2025-12-24 Working product, now based on ESP32-S3 Reverse TFT Feather and Arduino with absolutely horrible OpenSCAD quick and dirty model but it works
    [Enclosure (Reverse TFT).scad, Enclosure.scad]
2025-12-27 Replaced Fritzing with proper diagram
    [Fritzing.fzz]
2025-12-30 Power down more accessories before entering deep sleep
2025-12-30 Buncha changes: * PWM fadeout the backlight when entering sleep * Shut down various devices explicitly to save more power during deep sleep * Get rid of various unused variables or code that has no e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
2025-12-31 Massive refactor for OOP instead of one big file; avoid playing the same GIF twice in a row by storing in NVRAM the last GIF played
    [Application.cpp, GifRenderer.cpp]
2025-12-31 Clarified reset button behavior with D2
2025-12-31 Clarified wiring a bit
2026-02-20 Use % so components don't get rendered with F6
    [Enclosure (Reverse TFT).scad]
2026-03-02 Used DMA for GIF rendering for massively improved performance, explicitly sync WAV/GIF playback by dropping GIF frames if needed
2026-03-07 Fix potential offset in AV sync and thread safety for playback state
2026-03-08 Various performance improvements for faster time to first frame and more consistent 30 fps playback
2026-03-08 Only render partial frames if that's all that's needed, and PWM fade off the LCD backlight using low level hardware call to save CPU
2026-03-09 Hopefully fixed the pseudo part of the PRNG
    [Application.cpp]
